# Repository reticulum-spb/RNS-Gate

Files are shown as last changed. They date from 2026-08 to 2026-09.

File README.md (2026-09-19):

# RNS-Gate

## Objective

Create a standalone device for access and routing within the Reticulum Network Stack 

## Interfaces for accessing other network nodes

* Integrated:
  - LoRa module (E22/E32 via SPI)
  - WiFi
  - Bluetooth
  - 10/100 Ethernet
* External:
  - RNode (via USB or Bluetooth)
  - WiFi in monitor mode (via USB)
* Audio access and PTT control for connecting analog VHF and HF radios with soft modem implementation 
* Connection of DMR stations via USB (OpenGD77 firmware) 

## Access to user devices

* BlueTooth 
* IP via WiFi and Ethernet

## Implementation

A 3-component "tower":

* Single-board computer based on Orange Pi Zero (both the H2+ and the H3 variant — a single image boots on either)
* Add-on board with an E22/E32 LoRa module 
* Add-on board with an HF/VHF audio interface

## Device configuration

Web interface over IP

## Building with Docker

The build runs inside a container and the working tree is stored
in the named volume `rns-gate-build`. This allows the toolchain, download cache
(`dl/`), and ccache to be reused across builds.

```sh
cd Firmware
./docker-build.sh              # full build -> docker/output/sdcard.img
./docker-build.sh config       # reset .config from defconfig (fast)
./docker-build.sh menuconfig   # edit and export a candidate defconfig
```

`menuconfig` edits the release-specific `.config` in the volume and exports a
minimal defconfig to `docker/output/gate_zero_defconfig`. A full build always
reapplies the defconfig from the repository, so review the exported file first.
To make the changes permanent, use it to replace `system/br2_external/configs/gate_zero_defconfig`.

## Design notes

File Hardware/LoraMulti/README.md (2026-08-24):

# RNS-Gate Hardware

## Lora module

### Pinout

| E22  | Orange Pi Zero |
|---|---|
| SPI  | SPI1 (PA13, PA14, PA15, PA16) |
| Busy | PA11 |
| NRST | PA06 |
| DIO1 | PA12 |
| DIO2 | PA19 |
| RXEN | PA02 |
| TXEN | PA18 |

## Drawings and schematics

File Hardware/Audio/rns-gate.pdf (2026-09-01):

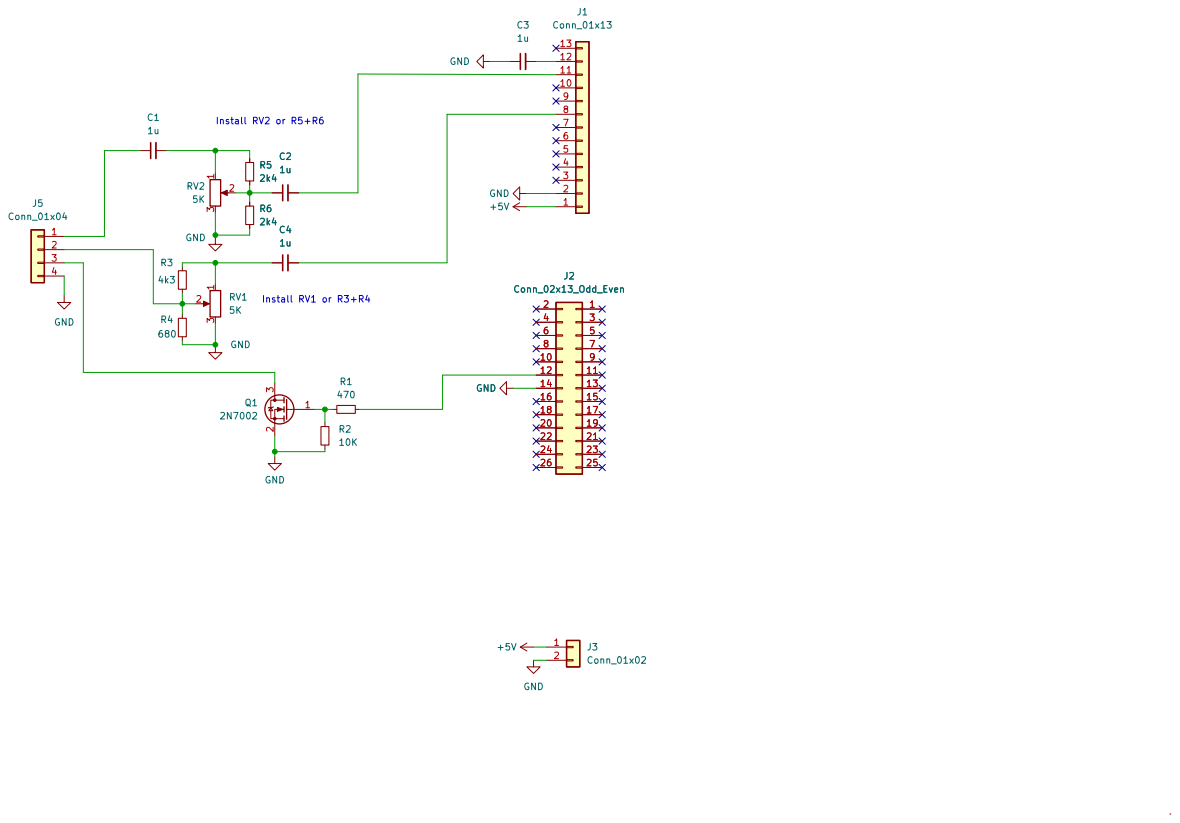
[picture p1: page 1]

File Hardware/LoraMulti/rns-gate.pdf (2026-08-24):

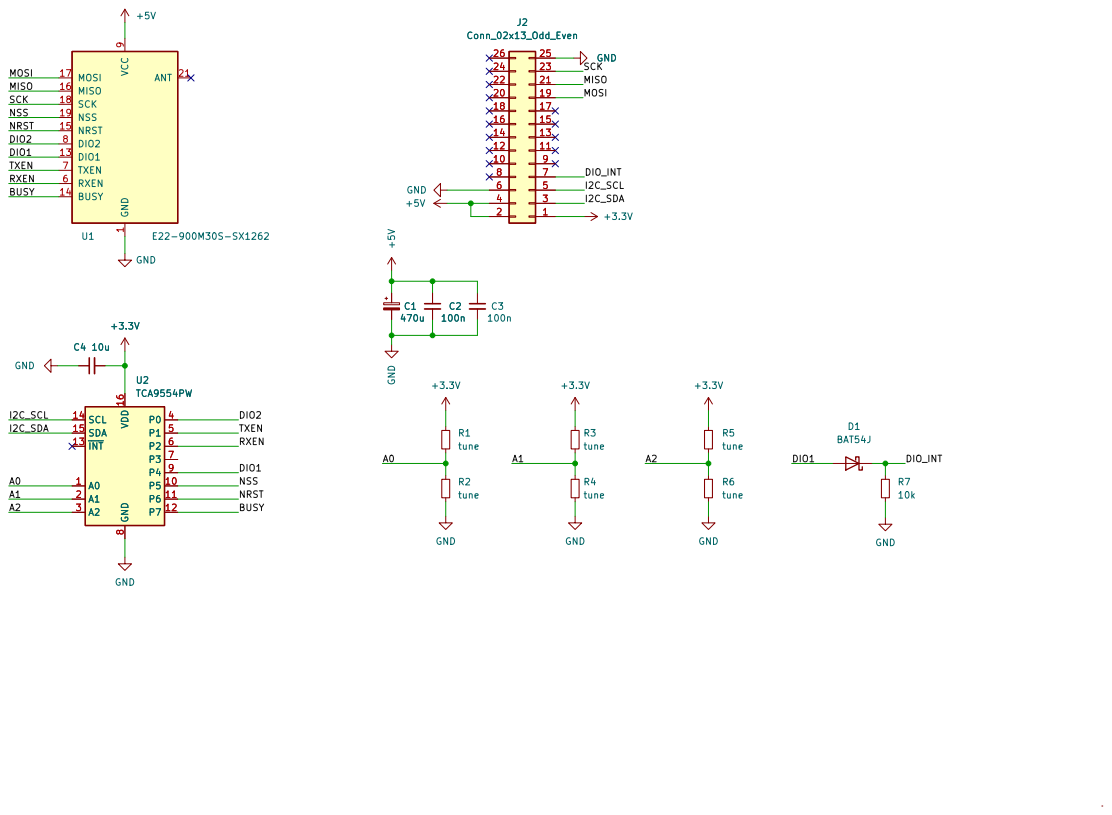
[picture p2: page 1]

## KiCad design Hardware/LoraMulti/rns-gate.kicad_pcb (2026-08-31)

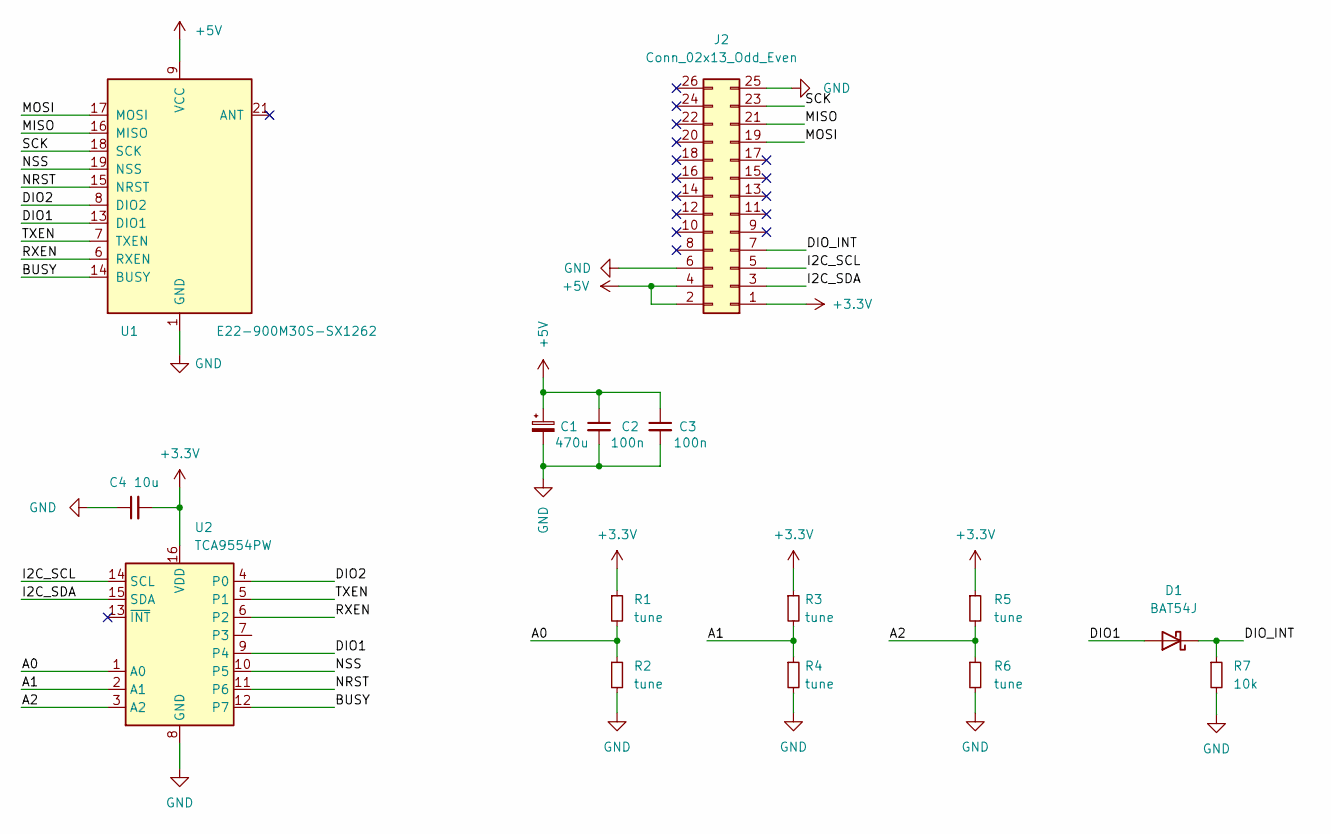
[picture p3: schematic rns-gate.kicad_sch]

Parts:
C1: 470u; CP_EIA-7343-43_Kemet-X_Pad2.25x2.55mm_HandSolder
C2, C3: 100n; C_0805_2012Metric_Pad1.18x1.45mm_HandSolder
C4: 10u; C_0805_2012Metric_Pad1.18x1.45mm_HandSolder
D1: BAT54J; D_SOD-323F
J2: Conn_02x13_Odd_Even; PinHeader_2x13_P2.54mm_Vertical
R1, R2, R3, R4, R5, R6: tune; R_0805_2012Metric
R7: 10k; R_0805_2012Metric
U1: E22-900M30S-SX1262
U2: TCA9554PW; TSSOP-16_4.4x5mm_P0.65mm

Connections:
+3.3V: C4.2, J2.1, R1.1, R3.1, R5.1, U2.16 (VDD)
+5V: C1.1, C2.1, C3.1, J2.2, J2.4, U1.9 (VCC), U1.10 (VCC)
/A0: R1.2, R2.1, U2.1 (A0)
/A1: R3.2, R4.1, U2.2 (A1)
/A2: R5.2, R6.1, U2.3 (A2)
/BUSY: U1.14 (BUSY), U2.12 (P7)
/DIO1: D1.2 (A), U1.13 (DIO1), U2.9 (P4)
/DIO2: U1.8 (DIO2), U2.4 (P0)
/DIO_INT: D1.1 (K), J2.7, R7.1
/I2C_SCL: J2.5, U2.14 (SCL)
/I2C_SDA: J2.3, U2.15 (SDA)
/MISO: J2.21, U1.16 (MISO)
/MOSI: J2.19, U1.17 (MOSI)
/NRST: U1.15 (NRST), U2.11 (P6)
/NSS: U1.19 (NSS), U2.10 (P5)
/RXEN: U1.6 (RXEN), U2.6 (P2)
/SCK: J2.23, U1.18 (SCK)
/TXEN: U1.7 (TXEN), U2.5 (P1)
GND: C1.2, C2.2, C3.2, C4.1, J2.6, J2.25, R2.2, R4.2, R6.2, R7.2, U1.1 (GND), U1.2 (GND), U1.3 (GND), U1.4 (GND), U1.5 (GND), U1.11 (GND), U1.12 (GND), U1.20 (GND), U1.22 (GND), U2.8 (GND)

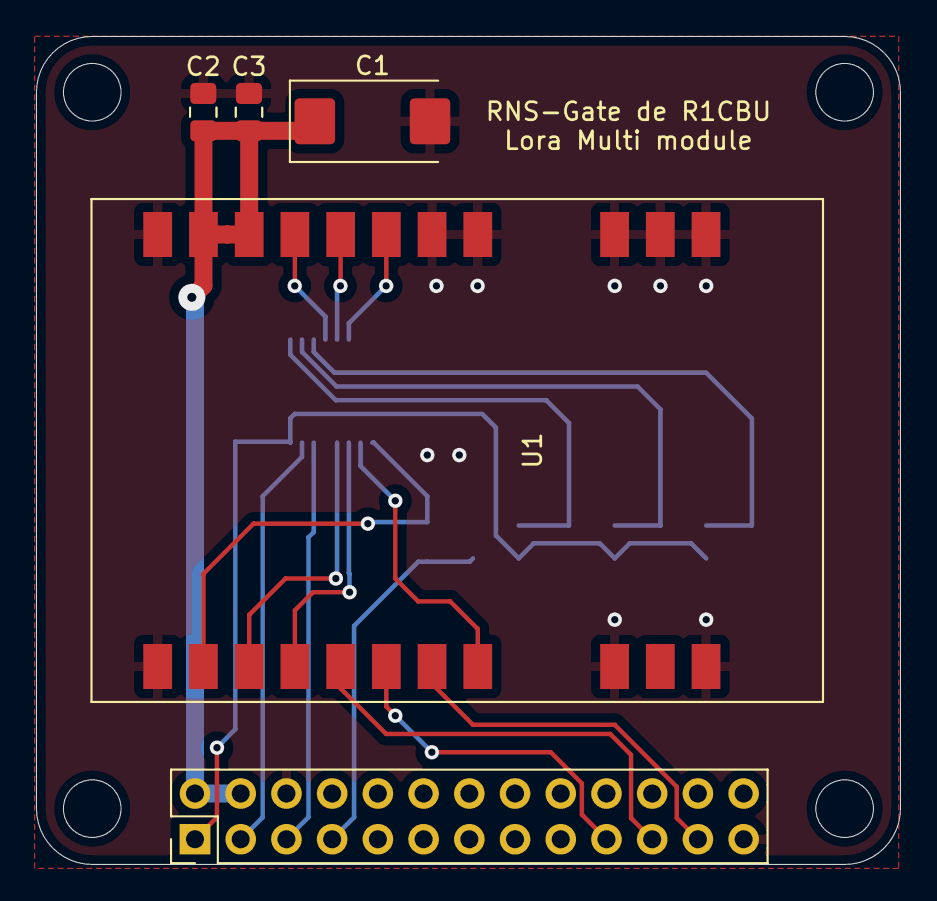
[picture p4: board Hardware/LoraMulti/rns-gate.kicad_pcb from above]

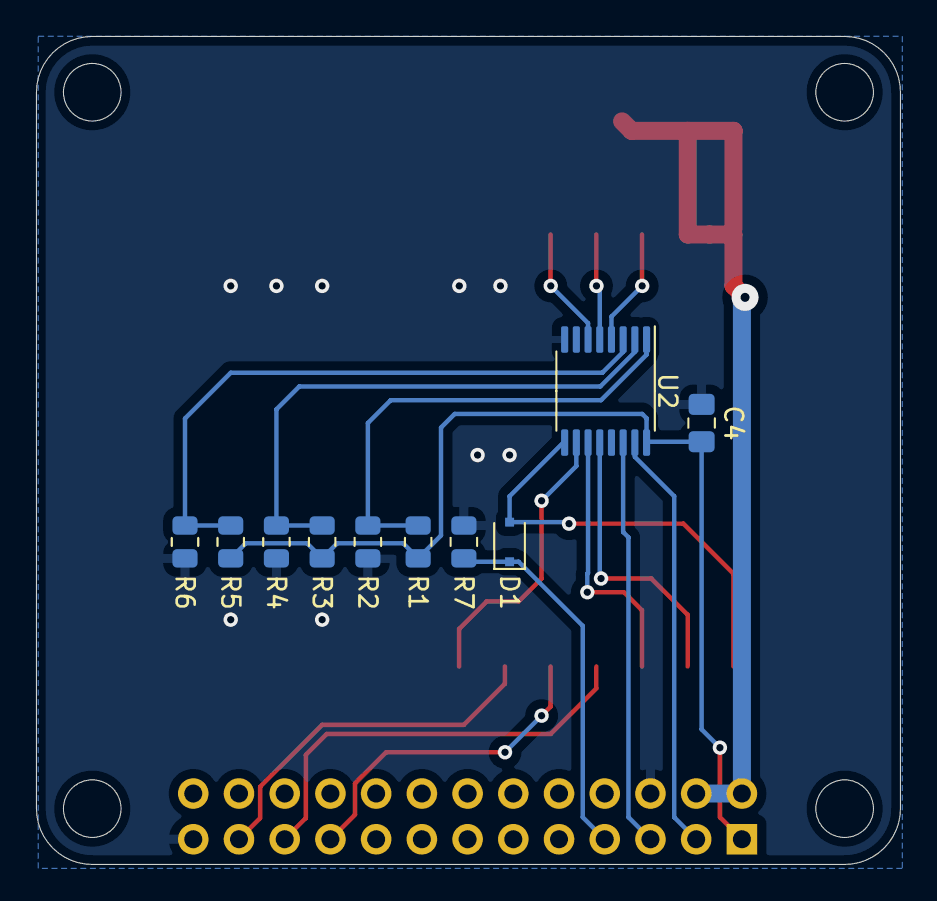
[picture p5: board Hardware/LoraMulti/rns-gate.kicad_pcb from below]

Board: 2 copper layers, 48.0 x 46.0 mm, 19 parts (10 on the bottom side), 19 nets.

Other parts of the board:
REF1, REF2, REF3, REF4: MountingHole_3.2mm_M3

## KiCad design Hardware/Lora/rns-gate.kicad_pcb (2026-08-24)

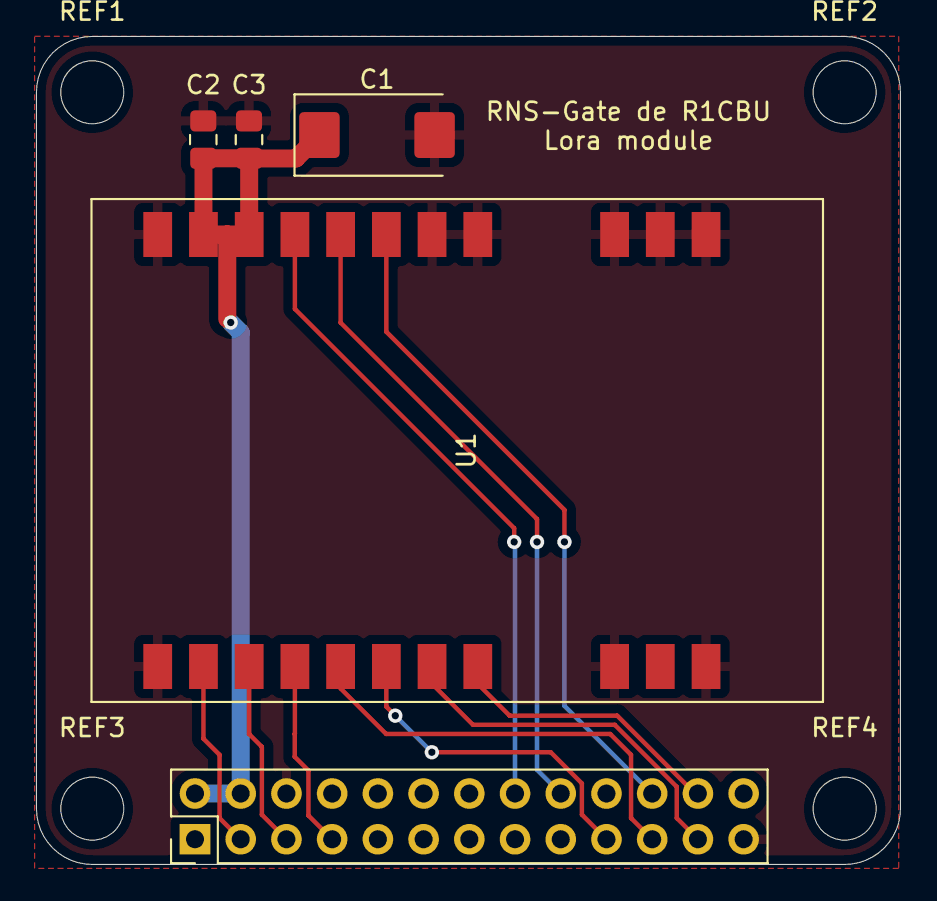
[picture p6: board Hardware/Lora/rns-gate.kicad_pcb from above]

Board: 2 copper layers, 48.0 x 46.0 mm, 9 parts (0 on the bottom side), 12 nets.

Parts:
C1: C_Polarized_Small; CP_EIA-7343-43_Kemet-X_Pad2.25x2.55mm_HandSolder
C2, C3: C_Small; C_0805_2012Metric_Pad1.18x1.45mm_HandSolder
J2: Conn_02x13_Odd_Even; PinHeader_2x13_P2.54mm_Vertical
REF1, REF2, REF3, REF4: MountingHole_3.5mm
U1: E22-900M30S-SX1262

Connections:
+5V: C1.1, C2.1, C3.1, J2.2, J2.4, U1.9 (VCC), U1.10 (VCC)
/BUSY: J2.5, U1.14 (BUSY)
/DIO1: J2.3, U1.13 (DIO1)
/DIO2: J2.16, U1.8 (DIO2)
/MISO: J2.21, U1.16 (MISO)
/MOSI: J2.19, U1.17 (MOSI)
/NRST: J2.7, U1.15 (NRST)
/NSS: J2.24, U1.19 (NSS)
/RXEN: J2.22, U1.6 (RXEN)
/SCK: J2.23, U1.18 (SCK)
/TXEN: J2.18, U1.7 (TXEN)
GND: C1.2, C2.2, C3.2, J2.6, J2.25, U1.1 (GND), U1.2 (GND), U1.3 (GND), U1.4 (GND), U1.5 (GND), U1.11 (GND), U1.12 (GND), U1.20 (GND), U1.22 (GND)

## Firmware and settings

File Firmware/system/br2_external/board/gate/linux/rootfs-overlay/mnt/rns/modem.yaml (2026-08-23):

hardware:
  audio_device: hw:0,0
  sample_rate_hz: 48000
  period_ms: 10
  periods: 4
  io_timeout_ms: 2000
  ptt:
    port: 0
    pin: 7
    active_high: true

profiles:
  # FEC mode: 0=NONE (tests), 1=ROBUST TC128 rate 1/2,
  #           2=NORMAL punctured TC128 rate 2/3.
  - id: 0
    name: bpsk_1200_1_8
    modulation: bpsk
    symbol_rate_baud: 1200
    carrier_hz: 1650.0
    rrc_rolloff: 0.25
    acquisition_threshold: 0.70
    training_threshold: 0.55
    detector_bandwidth_margin: 1.35
    fec_mode: 1
    payload_class_bytes: 8
  - id: 1
    name: bpsk_1200_1_64
    modulation: bpsk
    symbol_rate_baud: 1200
    carrier_hz: 1650.0
    rrc_rolloff: 0.25
    acquisition_threshold: 0.70
    training_threshold: 0.55
    detector_bandwidth_margin: 1.35
    fec_mode: 1
    payload_class_bytes: 64
  - id: 2
    name: qpsk_1200_1_64
    modulation: qpsk
    symbol_rate_baud: 1200
    carrier_hz: 1650.0
    rrc_rolloff: 0.25
    acquisition_threshold: 0.70
    training_threshold: 0.55
    detector_bandwidth_margin: 1.35
    fec_mode: 1
    payload_class_bytes: 64
  - id: 3
    name: qpsk_1600_1_64
    modulation: qpsk
    symbol_rate_baud: 1600
    carrier_hz: 1650.0
    rrc_rolloff: 0.25
    acquisition_threshold: 0.70
    training_threshold: 0.55
    detector_bandwidth_margin: 1.35
    fec_mode: 1
    payload_class_bytes: 64
  - id: 4
    name: qpsk_1600_1_128
    modulation: qpsk
    symbol_rate_baud: 1600
    carrier_hz: 1650.0
    rrc_rolloff: 0.25
    acquisition_threshold: 0.70
    training_threshold: 0.55
    detector_bandwidth_margin: 1.35
    fec_mode: 1
    payload_class_bytes: 128
  - id: 5
    name: qpsk_1600_2_64
    modulation: qpsk
    symbol_rate_baud: 1600
    carrier_hz: 1650.0
    rrc_rolloff: 0.25
    acquisition_threshold: 0.70
    training_threshold: 0.55
    detector_bandwidth_margin: 1.35
    fec_mode: 2
    payload_class_bytes: 64
  - id: 6
    name: qpsk_1600_2_128
    modulation: qpsk
    symbol_rate_baud: 1600
    carrier_hz: 1650.0
    rrc_rolloff: 0.25
    acquisition_threshold: 0.70
    training_threshold: 0.55
    detector_bandwidth_margin: 1.35
    fec_mode: 2
    payload_class_bytes: 128
  - id: 7
    name: qpsk1500_c1800_1_64
    modulation: qpsk
    symbol_rate_baud: 1500
    carrier_hz: 1800.0
    rrc_rolloff: 0.25
    acquisition_threshold: 0.90
    training_threshold: 0.70
    detector_bandwidth_margin: 1.35
    fec_mode: 1
    payload_class_bytes: 64
  - id: 8
    name: qpsk1600_c1300_1_64
    modulation: qpsk
    symbol_rate_baud: 1600
    carrier_hz: 1300.0
    rrc_rolloff: 0.25
    acquisition_threshold: 0.90
    training_threshold: 0.70
    detector_bandwidth_margin: 1.35
    fec_mode: 1
    payload_class_bytes: 64
  - id: 9
    name: qpsk1600_c1450_1_64
    modulation: qpsk
    symbol_rate_baud: 1600
    carrier_hz: 1450.0
    rrc_rolloff: 0.25
    acquisition_threshold: 0.90
    training_threshold: 0.70
    detector_bandwidth_margin: 1.35
    fec_mode: 1
    payload_class_bytes: 64
  - id: 10
    name: qpsk1600_c1800_1_64
    modulation: qpsk
    symbol_rate_baud: 1600
    carrier_hz: 1800.0
    rrc_rolloff: 0.25
    acquisition_threshold: 0.90
    training_threshold: 0.70
    detector_bandwidth_margin: 1.35
    fec_mode: 1
    payload_class_bytes: 64
  - id: 11
    name: qpsk_1920_1_64
    modulation: qpsk
    symbol_rate_baud: 1920
    carrier_hz: 1650.0
    rrc_rolloff: 0.25
    acquisition_threshold: 0.70
    training_threshold: 0.55
    detector_bandwidth_margin: 1.35
    fec_mode: 1
    payload_class_bytes: 64
  - id: 12
    name: qpsk_2000_1_64
    modulation: qpsk
    symbol_rate_baud: 2000
    carrier_hz: 1650.0
    rrc_rolloff: 0.25
    acquisition_threshold: 0.70
    training_threshold: 0.55
    detector_bandwidth_margin: 1.35
    fec_mode: 1
    payload_class_bytes: 64
  - id: 13
    name: qpsk_2400_1_64
    modulation: qpsk
    symbol_rate_baud: 2400
    carrier_hz: 1650.0
    rrc_rolloff: 0.25
    acquisition_threshold: 0.70
    training_threshold: 0.55
    detector_bandwidth_margin: 1.35
    fec_mode: 1
    payload_class_bytes: 64
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

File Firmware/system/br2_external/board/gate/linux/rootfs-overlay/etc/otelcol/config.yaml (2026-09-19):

# Run the collector with GOMEMLIMIT=64MiB and enforce a hard RSS limit with
# systemd/cgroup (for example, MemoryMax=96M).

extensions:
  #  file_storage:
  #    directory: /var/lib/otelarmv7col/storage
  #    create_directory: true
  #    # This is a limit for each bbolt database file, not for the whole directory.
  #    max_size: 67108864 # 64 MiB
  #    timeout: 1s
  #    fsync: false
  #    compaction:
  #      on_start: true
  #      on_rebound: true
  #      rebound_needed_threshold_mib: 32
  #      rebound_trigger_threshold_mib: 8
  #      cleanup_on_start: true
  basicauth/caddy:
    client_auth:
      username: otel-ingest
      password: piu45g89up9h834g98q34099--j0q3t4

receivers:
  hostmetrics:
    collection_interval: 15s
    scrapers:
      cpu:
      disk:
      load:
      filesystem:
      memory:
      network:
      paging:
      processes:
      process:
        mute_process_all_errors: true
      system:
      hardware:

  filelog/syslog:
    include:
      - /var/log/messages
    start_at: end
    max_concurrent_files: 4
    max_log_size: 64KiB
    max_log_size_behavior: truncate
    max_batches: 1
    operators:
      - type: syslog_parser
        protocol: rfc5424
        parse_from: body
        parse_to: attributes

      - type: move
        from: attributes.message
        to: body

  filelog/rns_application:
    include:
      - /mnt/rns/.rsReticulum/logfile
    start_at: end
    max_concurrent_files: 4
    max_log_size: 64KiB
    max_log_size_behavior: truncate
    max_batches: 1
    operators:
      - type: regex_parser
        id: parse_rns_log
        parse_from: body
        parse_to: attributes
        regex: '^(?P<timestamp>\S+)\s+(?P<severity_text>\w+)\s+(?P<appname>.+?):\s+(?P<message>.*)$'

        timestamp:
          parse_from: attributes.timestamp
          layout: '%Y-%m-%dT%H:%M:%S.%LZ'

      - type: move
        from: attributes.message
        to: body

      - type: severity_parser
        parse_from: attributes.severity_text

processors:
  memory_limiter:
    check_interval: 1s
    limit_mib: 32
    spike_limit_mib: 12
  batch:
    timeout: 10s
    send_batch_size: 128
    send_batch_max_size: 256
  attributes/device:
    actions:
      - key: device_mac
        value: ${env:DEVICE_MAC}
        action: upsert
      - key: system
        value: rns_gate
        action: upsert

exporters:
  otlp_http:
    endpoint: "https://metrics.nekoalex.dev"
    timeout: 10s
    auth:
      authenticator: basicauth/caddy
    compression: gzip
  #    sending_queue:
  #      enabled: true
  #      # A persistent queue has no in-memory queue. Keep one active request and
  #      # drop new batches when the bounded disk queue is full instead of
  #      # accumulating backpressure in RAM.
  #      storage: file_storage
  #      queue_size: 64
  #      num_consumers: 1
  #      block_on_overflow: false
  #    retry_on_failure:
  #      enabled: true
  #      initial_interval: 5s
  #      max_interval: 30s
  #      # The disk queue is bounded, so keep retrying queued data until it can be
  #      # delivered. Once it is full, newly produced batches are dropped.
  #      max_elapsed_time: 0s

service:
  extensions:
    - basicauth/caddy
  #    - file_storage
  #  telemetry:
  #    logs:
  #      level: warn
  #    metrics:
  #      # Export the collector's own CPU, RSS, Go heap, queue and pipeline
  #      # counters directly over OTLP. This does not require a Prometheus
  #      # receiver or a self-scrape pipeline.
  #      level: basic
  #      readers:
  #        - periodic:
  #            interval: 30000 # milliseconds
  #            timeout: 5000 # milliseconds
  #            exporter:
  #              otlp:
  #                protocol: grpc
  #                endpoint: 192.168.1.100:4317
  #                insecure: true
  pipelines:
    metrics:
      receivers: [ hostmetrics ]
      processors: [ attributes/device, memory_limiter, batch ]
      exporters: [ otlp_http ]
    logs:
      receivers: [ filelog/syslog, filelog/rns_application ]
      processors: [ attributes/device, memory_limiter, batch ]
      exporters: [ otlp_http ]

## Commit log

2026-06-24 Add Docker-based Buildroot image build
    The image previously had to be built on a Linux host with config.sh. This
    adds a self-contained Docker path so the same gate_zero_defconfig image
    can be produced from macOS without touching the host.
    1. docker/Dockerfile provisions a Debian Buildroot host and a non-root
    build user, since Buildroot refuses to configure several host packages
    as root.
    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
2026-06-24 Tee build output to a visible project-local log
    Build progress was invisible: the container streamed to stdout only, so a
    backgrounded run left no way to follow it and docker/output/ stayed empty
    until the final image copy.
    The wrapper now tees the full Buildroot output to docker/output/build.log,
    giving a predictable path to tail, and prints the grep recipe for the
    package-by-package timeline.
2026-08-19 Migrate SPI Lora to sx1262 plugin
2026-08-24 Update PCB, added LoraMulty board
    [rns-gate-B_Mask.gbs, rns-gate-B_Paste.gbp, rns-gate-B_Silkscreen.gbo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]
2026-08-31 refactor: fix typo in file
    [rns-gate.kicad_pcb]
2026-08-31 refactor: fix typo in directory
    [rns-gate-B_Mask.gbs, rns-gate-B_Paste.gbp, rns-gate-B_Silkscreen.gbo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]
2026-09-01 Clarification in the Audio module schematic
    [rns-gate.kicad_sch]
2026-09-02 fix: revert pin changes in config
    [config.yaml]
2026-09-05 fix: revert unnecessary wlan driver changes
